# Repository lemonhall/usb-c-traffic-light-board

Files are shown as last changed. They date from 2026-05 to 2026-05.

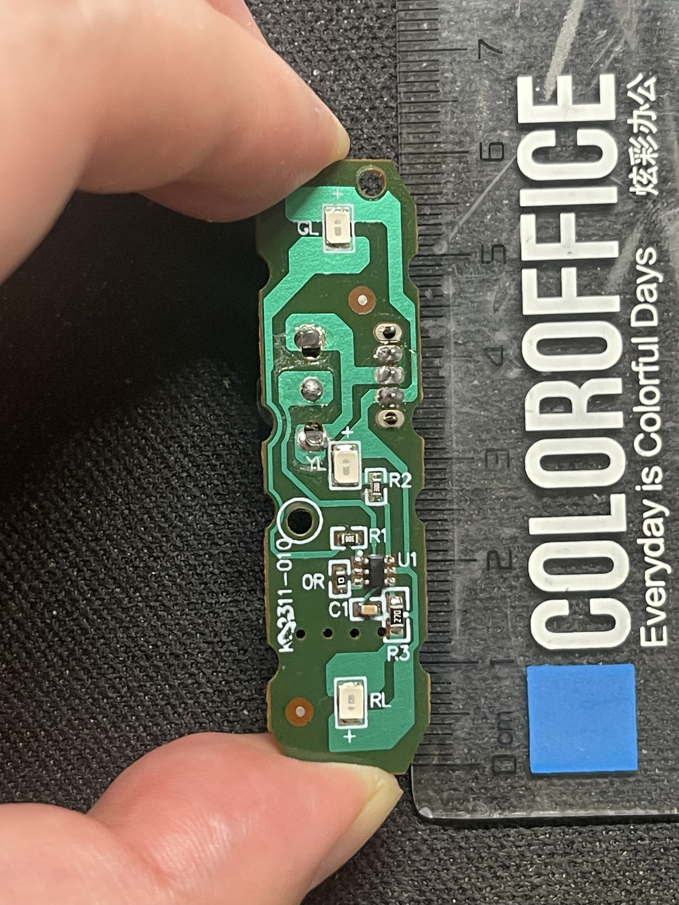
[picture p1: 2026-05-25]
references/正面.jpg

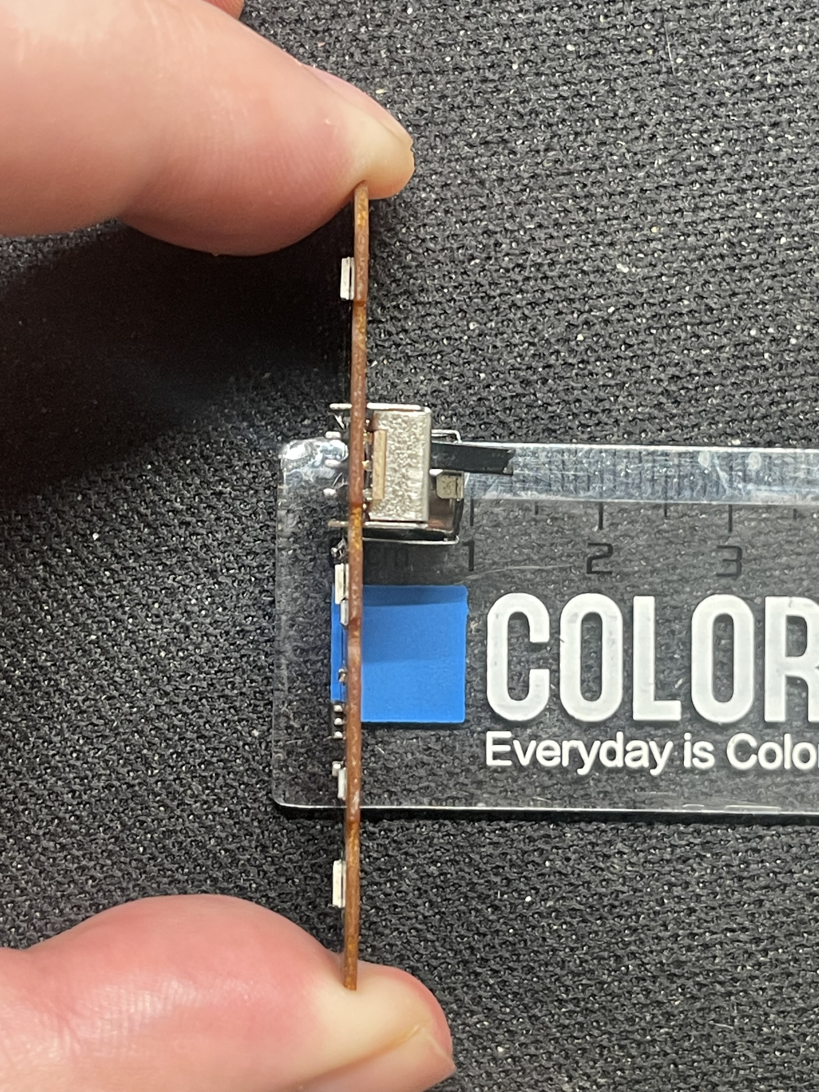
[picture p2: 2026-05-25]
references/侧面.jpg

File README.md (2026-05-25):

# USB-C 红绿灯控制板

这是一个用于替换原红绿灯小板的项目。目标是做一块新的 `57mm x 14mm` 电路板，通过 USB-C 供电，并让电脑通过 USB 串口控制红、黄、绿三颗灯。

## 目标

- 完全替换原来的小电路板。
- 使用 USB-C 供电。
- 通过 USB-C 连接电脑，由电脑控制三颗灯。
- 电脑端识别为虚拟串口，方便脚本控制。
- 尽量避免飞线，最终装配时只使用这一块新板。

## 当前机械假设

- 板长：`57mm`
- 板宽：`14mm`
- 当前板框已经按原板照片改成上下梯形端部和左右半圆避让槽。
- 三颗灯从上到下为：绿、黄、红；灯中心按从板底往上约 `50mm`、`28mm`、`7mm` 复核。
- 上螺丝孔直径 `2mm`，孔边离上端梯形窄边约 `1mm`。
- 下螺丝孔直径 `2mm`，孔中心离板顶约 `33mm`，位于板子左侧、靠近从下往上第二组避让槽。
- USB-C 目标位置对应原拨动开关穿出后壳的位置；原开关伸出背面约 `10mm`，开口宽度约 `10mm`。
- 注意：当前 KiCad 里 `USB_C_Receptacle_G-Switch_GT-USB-7025` 是 `right-angle` 占位封装，不是最终可下单的立式背出 USB-C；最终必须按实物型号替换封装和 3D 机械模型。

## 下一步顺序

1. 机械复核：量原板孔位、缺口、圆角、灯中心坐标、USB-C 后壳开口位置，把板框从当前矩形改成更贴原壳的形状。
2. USB-C 完整性复核：按最终采购的连接器封装，复核 `VBUS`、`GND`、`CC1`、`CC2`、`D+`、`D-`，确认正反插都能稳定供电和通信。
3. 生成生产文件：用 KiCad CLI 导出 Gerber 和钻孔文件，再用 Gerber 预览检查铜层、板框、孔、阻焊和丝印。
4. 小批打样前审查：逐项核对 BOM、封装方向、LED 极性、USB-C 型号、CH552G 供电和下载方式。

当前建议先做第 1 步和第 2 步。它们决定这块板能不能真的塞回外壳，以及插上电脑后能不能稳定识别。

## 电气方案

- 主控：沁恒 `CH552G`，小封装、带原生 USB。
- USB-C：
  - 电脑 USB-C 默认 `VBUS` 提供 `5V`。
  - 本板只作为普通受电设备，不做 USB PD 高压协商。
  - `D+ / D-` 接到主控 USB 引脚。
  - `CC1 / CC2` 各接一个 `5.1k` 下拉电阻到地，只做受电设备。
- 三颗灯：
  - 每颗灯单独串限流电阻。
  - 每颗灯由一个主控 GPIO 控制。
  - 固件可用 PWM 分别控制三颗灯亮度，也可以控制任意组合同时亮、闪烁或呼吸。
  - 第一版按低亮度指示灯设计，目标电流约 `2-5mA`。
- 调试：
  - 预留 `5V`、`GND`、`D+`、`D-`、复位、三路灯控制测试焊盘。

## 串口协议草案

电脑通过虚拟串口发送一行文本命令：

```text
R 1
R 0
Y 1
Y 0
G 1
G 0
A 0
A 1
S 1 0 1
?
```

返回示例：

```text
OK
ERR 1
S R=1 Y=0 G=1
```

## 文件说明

- `docs/hardware/requirements.md`：需求和边界。
- `docs/hardware/bom.md`：第一版物料清单。
- `docs/hardware/pinout.md`：引脚和网络分配。
- `docs/hardware/mechanical-measurement-guide.md`：原板外轮廓和孔位测量指南。
- `docs/hardware/serial-protocol.md`：电脑控制协议。
- `docs/hardware/schematic.md`：完整原理图连接说明。
- `docs/hardware/schematic.svg`：可直接打开查看的完整原理图。
- `docs/hardware/pcb-layout.svg`：第一版 PCB 顶层布局草案。
- `references/original-board-photo.md`：原板照片观察记录。
- `kicad/`：KiCad 工程骨架和第一版板框。
- `firmware/README.md`：固件设计说明。
- `pc-control/traffic_light.py`：电脑端串口控制小脚本。

## 已查资料

- CH552G 是带 USB 的 8 位单片机：https://www.alldatasheet.com/datasheet-pdf/pdf/1147065/WCH/CH552G.html
- LCSC 页面显示 CH552G 常见封装为 SOP-16：https://www.lcsc.com/product-detail/Microcontrollers-MCU-MPU-SOC_WCH-Jiangsu-Qin-Heng-CH552G_C111292.html
- CH552G 资料中包含 USB Type-C CC 控制相关内容：https://www.alldatasheet.net/html-pdf/1147065/WCH/CH552G/2781/41/CH552G.html

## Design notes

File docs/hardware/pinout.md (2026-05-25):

# 引脚和网络分配草案

## USB-C

| 信号 | 连接位置 | 说明 |
| --- | --- | --- |
| USB_C_VBUS | 主控电源 / 板上 `5V` | C1 靠近 USB-C 插座 |
| USB_C_GND | 板上地 | USB-C 外壳附近多打地过孔 |
| USB_D_PLUS | 通过 R4 接主控 USB D+ | 走线尽量短，并和 D- 成对 |
| USB_D_MINUS | 通过 R5 接主控 USB D- | 走线尽量短，并和 D+ 成对 |
| USB_CC1 | `5.1k` 到地 | 声明自己是受电设备 |
| USB_CC2 | `5.1k` 到地 | 声明自己是受电设备 |

## 三路灯控制

以下按 CH552G 的 SOP-16 引脚整理。下单前仍要对照最终采购型号的数据手册和封装丝印再核一次。

| 功能 | 网络名 | 主控物理脚 | 主控端口 | 驱动方式 |
| --- | --- | --- | --- | --- |
| 红灯 | LED_R | 2 脚 | P1.4 | GPIO 输出高电平点亮 |
| 黄灯 | LED_Y | 3 脚 | P1.5 | GPIO 输出高电平点亮 |
| 绿灯 | LED_G | 4 脚 | P1.6 | GPIO 输出高电平点亮 |

## CH552G SOP-16 关键引脚

| 物理脚 | 名称 | 本项目用途 |
| ---: | --- | --- |
| 1 | P3.2 | 预留 |
| 2 | P1.4 | 红灯控制 |
| 3 | P1.5 | 黄灯控制 |
| 4 | P1.6 | 绿灯控制 |
| 5 | P1.7 | 预留 |
| 6 | RST | 复位 / 测试焊盘 |
| 7 | P3.1 | 预留 |
| 8 | P3.0 | 预留 |
| 9 | P1.1 | 预留 |
| 10 | P3.3 | 预留 |
| 11 | P3.4 | 预留 |
| 12 | P3.6 / UDP | USB D+ |
| 13 | P3.7 / UDM | USB D- |
| 14 | GND | 地 |
| 15 | VCC | `5V` |
| 16 | V33 | 内部 USB 稳压输出，接 `100nF` 到地 |

## 测试焊盘

| 焊盘 | 网络名 | 用途 |
| --- | --- | --- |
| TP1 | 5V | 量供电 |
| TP2 | GND | 接地夹 |
| TP3 | USB_D_PLUS | USB 调试 |
| TP4 | USB_D_MINUS | USB 调试 |
| TP5 | RST | 复位 / 烧录辅助 |
| TP6 | LED_R | 红灯信号探针 |
| TP7 | LED_Y | 黄灯信号探针 |
| TP8 | LED_G | 绿灯信号探针 |

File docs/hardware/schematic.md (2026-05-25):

# 完整原理图说明

这份原理图对应文件：

- `docs/hardware/schematic.svg`

可以直接用浏览器、图片查看器或矢量图软件打开。

## 电源

USB-C 的 `VBUS` 作为板上 `5V` 电源。`C1` 是输入储能电容，`C2` 靠近主控 `VCC`，`C3` 靠近主控 `V33`。

CH552G 在 `5V` 供电时：

- `VCC` 接 `5V`。
- `GND` 接地。
- `V33` 接 `100nF` 到地，不直接给外部负载供电。

## USB-C

- `A6` 和 `B6` 合并为 USB D+。
- `A7` 和 `B7` 合并为 USB D-。
- D+ 经过 `R4 22Ω` 接 CH552G 的 `P3.6/UDP`。
- D- 经过 `R5 22Ω` 接 CH552G 的 `P3.7/UDM`。
- `CC1` 经过 `R6 5.1k` 接地。
- `CC2` 经过 `R7 5.1k` 接地。

## 三颗灯

第一版采用“GPIO 输出高电平点亮”的接法：

- `P1.4` 控红灯。
- `P1.5` 控黄灯。
- `P1.6` 控绿灯。

每路结构相同：

```text
主控 GPIO -> 限流电阻 -> LED -> GND
```

第一版限流电阻用 `1k`，适合做室内状态指示。若透光件较暗，可以改为 `680Ω` 或 `470Ω` 后实测亮度。

## 复位和测试点

- `RST` 预留测试焊盘，默认上拉/复位电路按 CH552G 参考设计最终确认。
- 预留 `5V`、`GND`、`D+`、`D-`、`RST`、`红灯`、`黄灯`、`绿灯` 测试点。

## 下单前必须复核

- USB-C 母座封装是否与实际购买型号一致。
- CH552G SOP-16 封装方向和 1 脚标记。
- 三颗灯是否正好对准外壳透光孔。
- 板框缺口、圆角、安装孔是否符合实物。

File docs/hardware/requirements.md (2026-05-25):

# 需求说明

## 产品目标

做一块 USB-C 控制的三灯红绿灯替换板。

## 必须满足

- 板子外形先按 `57mm x 14mm` 处理。
- 完全替换原板，不依赖原来的控制芯片。
- 使用 USB-C 同时完成供电和电脑控制。
- 三颗灯可以独立控制：
  - 红灯
  - 黄灯
  - 绿灯
- 最终装配尽量不飞线。
- 控制协议要能被电脑脚本直接调用。

## 应该满足

- 物料尽量选择国内常见、容易打样和焊接的器件。
- 原理图保持简单，方便手工排查。
- 关键电源和信号都留测试焊盘。

## 第一版不做

- 不做 Wi-Fi。
- 不做蓝牙。
- 不做电池充电。
- 不做 USB PD 协议协商。
- 不做大功率高亮 LED 驱动。
- 在精确尺寸出来前，不强行复刻全部缺口和孔位。

## 仍需补充的机械尺寸

- 三颗灯的中心坐标。
- 安装孔直径和中心坐标。
- 侧边缺口、倒角、圆角尺寸。
- USB-C 插座在外壳里的露出和避让空间。

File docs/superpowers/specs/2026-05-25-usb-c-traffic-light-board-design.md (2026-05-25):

# USB-C 红绿灯控制板设计

## 目的

做一块完整替换原红绿灯小板的新 PCB。新板通过 USB-C 供电，并通过 USB CDC 虚拟串口接受电脑控制。

## 机械范围

第一版板框使用 `57mm x 14mm` 矩形。三颗灯的位置先按照片大致竖向排列，等你提供卡尺尺寸后再精修。板上需要容纳三颗 LED、USB-C 母座、CH552G 主控、USB 阻容、LED 限流电阻和测试焊盘。

## 电气范围

主控使用带原生 USB 的 CH552G，而不是 ESP32，因为本需求不需要 Wi-Fi 或蓝牙。USB-C 提供 `5V` 供电以及 USB2.0 的 `D+ / D-` 数据线。`CC1 / CC2` 使用外置 `5.1k` 下拉电阻声明受电设备。每颗 LED 由一个 GPIO 通过限流电阻独立控制。

## 控制协议

电脑通过虚拟串口发送 ASCII 文本命令，例如 `R 1`、`Y 0`、`G 1`、`A 0`、`S 1 0 1` 和 `?`。板子返回 `OK`、当前状态或解析错误。

## 第一版交付物

- 项目说明。
- 需求说明。
- 物料清单。
- 引脚分配。
- 串口协议。
- KiCad 工程骨架。
- 第一版板框。
- 完整原理图 SVG。
- PCB 顶层布局草案 SVG。
- 电脑端串口控制脚本。

## 风险

- CH552G 的物理引脚必须在最终 KiCad 符号和封装选定后再次核对。
- USB-C 母座封装必须和最终采购型号一致。
- 三颗灯中心、安装孔和缺口需要精确尺寸后才能打样。
- 固件需要先选定一个稳定的 CH55x CDC 示例工程。

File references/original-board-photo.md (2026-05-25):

# 原板照片记录

当前已保存三张参考图：

```text
references/正面.jpg
references/背面.jpg
references/侧面.jpg
```

## 从附件观察到的信息

- 原板是一块很窄的红绿灯小板。
- 三颗贴片 LED 竖向排列。
- 丝印大致如下：
  - 顶部灯附近是 `GL`
  - 中间灯附近是 `YL`
  - 底部灯附近是 `RL`
- 原板上有一个小控制芯片，丝印位置为 `U1`。
- 原板有较大的焊点，也有不规则侧边缺口。
- 外轮廓不是矩形：
  - 两端都有近似梯形倒角，外接宽度 `14mm`，端部窄边约 `10mm`，梯形高度约 `4-5mm`。
  - 两条长边共有 8 个半圆/浅槽避让，左右两两对齐，形成 4 组。
  - 4 组避让槽从板底往上约在 `10mm`、`23mm`、`32mm`、`46mm` 处。
  - 两个大圆孔是螺丝孔，实测孔径为 `2mm`。
- 背面能看到原拨动开关穿出板面，后续 USB-C 应尽量复用这个外壳开口方向，而不是放在板端。
- 侧面照片显示原拨动开关本体明显高出板面；新 USB-C 连接器必须复核高度和外壳干涉。
- 你实测的新板参考尺寸：
  - 长度：`57mm`
  - 宽度：`14mm`

## 当前 KiCad 机械近似

- `scripts/generate_kicad_pcb.py` 已按照片加入第一版近似外轮廓。
- 当前板框仍以 `57mm x 14mm` 为外接矩形基准。
- 上下端倒角按端部窄边 `10mm`、梯形高度 `4.5mm` 建模。
- 已加入两个 `2mm` 螺丝孔：
  - `H1`：靠近绿灯端。
  - `H2`：靠近中部偏黄灯/主控区域。
- 侧边避让槽已按 4 组左右对齐放置：
  - 从板底往上约 `10mm`、`23mm`、`32mm`、`46mm`。
  - 换算到当前 KiCad 坐标约为 `y=47mm`、`34mm`、`25mm`、`11mm`。
- 侧边避让槽深度仍为照片估算，后续需要试装或卡尺数据修正。

## 后续最好补充

- 两个螺丝孔中心距。
- 每个螺丝孔中心到板端、板边的距离。
- USB-C 预期开口中心到板端、板边的距离。

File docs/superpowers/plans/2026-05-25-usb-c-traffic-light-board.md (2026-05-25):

# USB-C 红绿灯控制板实施计划

> 给后续执行者：按任务逐项完成并勾选。每一步都应该留下可检查的文件结果。

**目标：** 建立一套第一版 USB-C 红绿灯控制板项目资料，面向 `57mm x 14mm` 完全替换板。

**架构：** 电路板使用 CH552G 原生 USB 单片机，USB-C 负责供电和数据，三颗 LED 由三个 GPIO 控制。KiCad 先建立工程骨架和板框，详细封装和精确机械位置等拿到卡尺数据后再锁定。

**技术栈：** KiCad、Markdown 硬件文档、Python 电脑端串口脚本。

---

### 任务 1：项目结构和需求

**文件：**
- 创建：`README.md`
- 创建：`docs/hardware/requirements.md`
- 创建：`references/original-board-photo.md`

- [x] **步骤 1：创建项目目录**

运行：

```powershell
New-Item -ItemType Directory -Force -Path E:\development\usb-c-traffic-light-board
```

期望结果：项目目录存在。

- [x] **步骤 2：写入需求文档**

写入 README、硬件需求和原板照片观察记录，明确 `57mm x 14mm` 外形、USB-C 供电控制、原板三灯信息。

### 任务 2：电气草案

**文件：**
- 创建：`docs/hardware/bom.md`
- 创建：`docs/hardware/pinout.md`
- 创建：`docs/hardware/serial-protocol.md`

- [x] **步骤 1：定义第一版物料清单**

列出 USB-C 母座、CH552G、三颗 LED、电阻、电容和测试焊盘。

- [x] **步骤 2：定义 USB 和 GPIO 网络**

记录 `VBUS`、`GND`、`D+`、`D-`、`CC1`、`CC2` 和三路 LED 控制信号。

- [x] **步骤 3：定义串口文本协议**

记录 `R`、`Y`、`G`、`A`、`S` 和 `?` 命令，以及对应返回。

### 任务 3：KiCad 骨架

**文件：**
- 创建：`kicad/usb_c_traffic_light_board.kicad_pro`
- 创建：`kicad/usb_c_traffic_light_board.kicad_sch`
- 创建：`kicad/usb_c_traffic_light_board.kicad_pcb`

- [x] **步骤 1：创建 KiCad 项目文件**

创建 KiCad 项目容器。

- [x] **步骤 2：创建原理图说明页**

创建带项目标题和设计说明的原理图草稿。

- [x] **步骤 3：创建板框**

创建 `57mm x 14mm` 的 `Edge.Cuts` 矩形板框，并加入放置提示。

### 任务 4：电脑端控制辅助

**文件：**
- 创建：`pc-control/traffic_light.py`
- 创建：`firmware/README.md`

- [x] **步骤 1：创建串口控制脚本**

实现一个最小 Python 脚本：向指定串口发送一条 ASCII 命令，并打印一行返回。

- [x] **步骤 2：记录固件行为**

记录上电状态、命令解析流程和可选工具链。

### 任务 5：验证

**文件：**
- 检查所有创建的文件。

- [x] **步骤 1：列出生成文件**

运行：

```powershell
Get-ChildItem -Recurse E:\development\usb-c-traffic-light-board
```

期望结果：计划中的文件都存在。

- [x] **步骤 2：检查中文乱码**

按仓库编码规则运行乱码特征扫描。

期望结果：没有匹配。

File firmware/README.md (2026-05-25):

# 固件说明

目标主控：CH552G。

固件行为：

1. 枚举为 USB CDC 虚拟串口设备。
2. 初始化红、黄、绿三个 GPIO 为输出。
3. 复位后默认三颗灯全灭。
4. 从虚拟串口读取一行 ASCII 命令。
5. 按 `docs/hardware/serial-protocol.md` 解析命令。
6. 返回 `OK`、当前状态，或错误信息。

## 状态流程草案

```text
USB 复位
  -> 初始化时钟和 USB 设备
  -> 初始化 GPIO 输出为低电平
  -> 等待串口命令行
  -> 解析命令
  -> 更新三颗灯状态
  -> 返回执行结果
  -> 等待下一条命令
```

## 构建工具

工具链还没有锁死。实用选择有：

- 沁恒官方 8051 开发流程。
- 基于 SDCC 的 CH55x 开发流程。

第一目标是先找到稳定的 CDC 示例工程；只要串口协议不变，底层工具链后续可以替换。

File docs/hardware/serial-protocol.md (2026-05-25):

# USB 虚拟串口控制协议

传输方式：USB CDC 虚拟串口。

换行：支持 `\n` 或 `\r\n`。

编码：ASCII。

## 命令

| 命令 | 含义 |
| --- | --- |
| `R 1` | 打开红灯 |
| `R 0` | 关闭红灯 |
| `Y 1` | 打开黄灯 |
| `Y 0` | 关闭黄灯 |
| `G 1` | 打开绿灯 |
| `G 0` | 关闭绿灯 |
| `A 1` | 三颗灯全开 |
| `A 0` | 三颗灯全关 |
| `S r y g` | 一次设置红、黄、绿三个状态，每个值为 `0` 或 `1` |
| `?` | 查询当前状态 |

## 返回

| 返回 | 含义 |
| --- | --- |
| `OK` | 命令已接受 |
| `S R=0 Y=0 G=0` | 当前状态 |
| `ERR 1` | 命令或参数无法解析 |

## 上电状态

USB 复位后，三颗灯默认全灭。

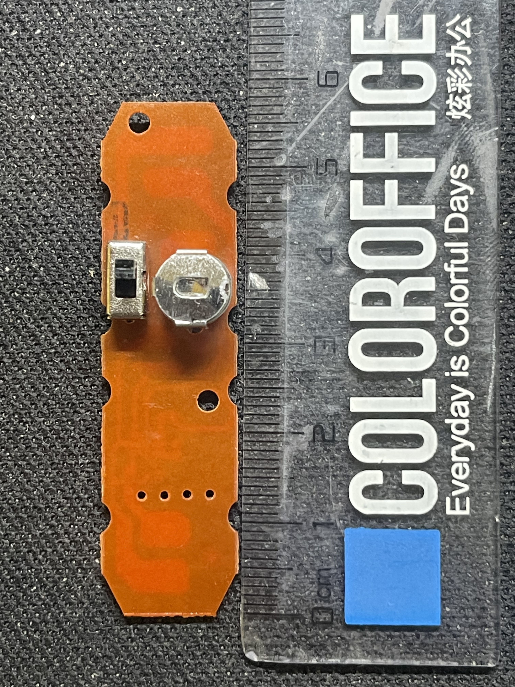
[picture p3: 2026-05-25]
references/背面.jpg

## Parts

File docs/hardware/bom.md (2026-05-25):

# 第一版物料清单

| 位号 | 数量 | 器件 | 封装 | 说明 |
| --- | ---: | --- | --- | --- |
| J1 | 1 | USB-C 母座 | 只接 USB2.0 的贴片座 | 等确认外壳后选择沉板或普通贴片 |
| U1 | 1 | 沁恒 CH552G | SOP-16 | 带原生 USB 的单片机 |
| D1 | 1 | 绿灯 LED | 0805 或 1206 | 按外壳透光孔选择尺寸 |
| D2 | 1 | 黄灯 LED | 0805 或 1206 | 按外壳透光孔选择尺寸 |
| D3 | 1 | 红灯 LED | 0805 或 1206 | 按外壳透光孔选择尺寸 |
| R1 | 1 | 绿灯限流电阻 | 0603 或 0805 | 第一版从 `1k` 起步 |
| R2 | 1 | 黄灯限流电阻 | 0603 或 0805 | 第一版从 `1k` 起步 |
| R3 | 1 | 红灯限流电阻 | 0603 或 0805 | 第一版从 `1k` 起步 |
| R4 | 1 | USB D+ 串联电阻 | 0603 | 第一版按 `22Ω` 预留 |
| R5 | 1 | USB D- 串联电阻 | 0603 | 第一版按 `22Ω` 预留 |
| R6 | 1 | CC1 下拉电阻 | 0603 | `5.1k` 到地 |
| R7 | 1 | CC2 下拉电阻 | 0603 | `5.1k` 到地 |
| C1 | 1 | VBUS 输入电容 | 0805 | `4.7uF` 或 `10uF` |
| C2 | 1 | 主控去耦电容 | 0603 | `100nF`，靠近 U1 |
| C3 | 1 | USB/内部电源去耦 | 0603 | `100nF`，最终按参考设计确认 |
| TP1-TP8 | 8 | 测试焊盘 | 约 `1.0mm` 焊盘 | `5V`、地、USB、复位、三路灯 |

## 说明

- 第一版主控选 CH552G，是因为它小、便宜，并且自带 USB。
- LED 电阻先按室内指示灯亮度设计，实际亮度要结合外壳透光效果再调。
- 如果 USB-C 会频繁插拔，第二版建议加 USB 静电保护器件。
- 当前完整连接图见 `docs/hardware/schematic.svg`。

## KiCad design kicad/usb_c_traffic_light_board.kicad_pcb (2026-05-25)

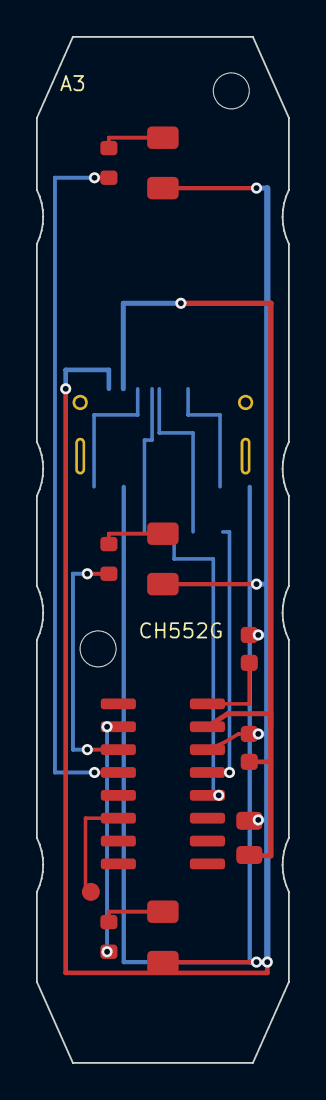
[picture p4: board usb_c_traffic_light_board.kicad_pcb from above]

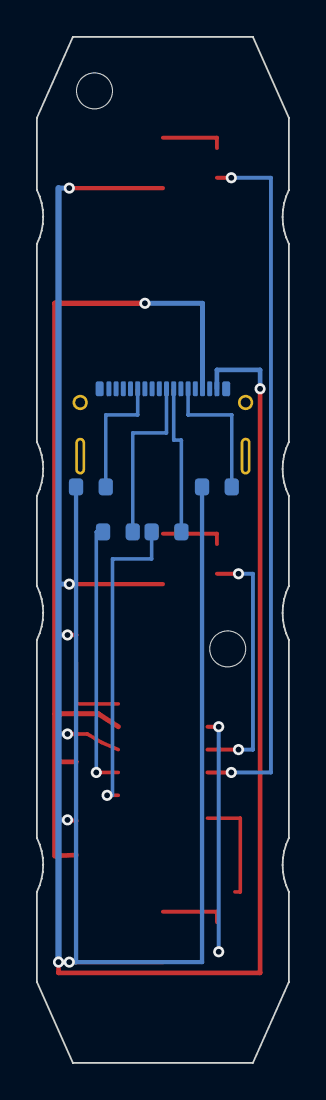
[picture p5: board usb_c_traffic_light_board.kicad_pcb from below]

Board: 2 copper layers, 14.0 x 57.0 mm, 18 parts (5 on the bottom side), 16 nets.

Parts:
C1: 10uF; C_0805_2012Metric
C2, C3: 100nF; C_0603_1608Metric
D1: 绿灯; LED_1206_3216Metric
D2: 橙灯; LED_1206_3216Metric
D3: 红灯; LED_1206_3216Metric
H1: 上螺丝孔; MountingHole_2mm
H2: 下螺丝孔; MountingHole_2mm
J1: 背面USB-C; USB_C_Receptacle_G-Switch_GT-USB-7025
R1, R2, R3: 1k; R_0603_1608Metric
R4, R5: 22R; R_0603_1608Metric
R6, R7: 5.1k; R_0603_1608Metric
TP1: RST; TestPoint_Pad_D1.0mm
U1: CH552G; SOIC-16_3.9x9.9mm_P1.27mm

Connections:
5V: C1.1, C2.1, J1.A4, U1.15
CC1: J1.A5, R6.1
CC2: J1.B5, R7.1
GND: C1.2, C2.2, C3.2, D1.1, D2.1, D3.1, J1.A1, R6.2, R7.2, U1.14
LED_G: R3.1, U1.4
LED_G_A: D1.2, R3.2
LED_R: R1.1, U1.2
LED_R_A: D3.2, R1.2
LED_Y: R2.1, U1.3
LED_Y_A: D2.2, R2.2
RST: TP1.1, U1.6
USB_D+: R4.2, U1.12
USB_D+_CONN: J1.A6, R4.1
USB_D-: R5.2, U1.13
USB_D-_CONN: J1.A7, R5.1
V33: C3.1, U1.16

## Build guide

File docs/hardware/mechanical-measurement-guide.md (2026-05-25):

# 机械复核测量指南

目标是把原板外轮廓、两个螺丝孔、三颗灯中心、USB-C 后壳开口位置复刻到新板上。不要只靠手持尺子量轮廓，误差会很大；优先用可标定图片来描边。

## 推荐方法一：扫描仪

如果有平板扫描仪，这是最稳的方法。

1. 把原板正面朝下放在扫描仪玻璃上，旁边放一把钢尺或游标卡尺。
2. 扫描分辨率设为 `600dpi` 或更高。
3. 导出 `PNG`，不要用会压缩变形的截图。
4. 再把原板背面也扫一张，用来确认背面开关/USB-C 开口对应位置。
5. 文件命名建议：
   - `references/original-board-front-600dpi.png`
   - `references/original-board-back-600dpi.png`

有扫描图以后，可以用已知板长 `57mm` 或板宽 `14mm` 做比例标定，再在 KiCad 里描 `Edge.Cuts`。

## 推荐方法二：手机正射照片

如果没有扫描仪，用手机也可以，但要尽量减少透视变形。

1. 把原板放在白纸上，旁边放钢尺或游标卡尺，尺子要和板子同一平面。
2. 手机镜头尽量正对板子中心，不要斜拍。
3. 用 `2x` 或 `3x` 镜头，手机离远一点拍，能减少边缘畸变。
4. 打开网格线，让板子长边尽量和画面竖线平行。
5. 拍正面、背面各一张，最好再拍一张带外壳开口位置的照片。
6. 不要裁剪，不要加滤镜，直接发原图。

## 必须量的尺寸

用游标卡尺直接量这些关键尺寸即可，不需要把每个斜边都量出来。

| 编号 | 项目 | 怎么量 |
| --- | --- | --- |
| M1 | 板总长 | 顶部最高点到最底部最低点 |
| M2 | 板最大宽 | 左右最宽处 |
| M3 | 上螺丝孔直径 | 孔内径 |
| M4 | 下螺丝孔直径 | 孔内径 |
| M5 | 两孔中心距 | 上孔中心到下孔中心 |
| M6 | 上孔中心到板顶 | 沿板长方向量 |
| M7 | 下孔中心到板底 | 沿板长方向量 |
| M8 | 上孔中心到左边 | 沿板宽方向量 |
| M9 | 下孔中心到左边 | 沿板宽方向量 |
| M10 | 绿灯中心到板顶 | 用灯珠中心估算 |
| M11 | 黄灯中心到板顶 | 用灯珠中心估算 |
| M12 | 红灯中心到板顶 | 用灯珠中心估算 |
| M13 | USB-C 外壳开口中心到板顶 | 按原拨动开关穿壳位置量 |
| M14 | USB-C 外壳开口中心到板左边 | 按原拨动开关穿壳位置量 |

## 外轮廓怎么给

外轮廓不用逐段精确手量。最实用的做法是：

1. 先用扫描图或正射照片描出轮廓。
2. 用 `57mm x 14mm` 标定比例。
3. 再用 M1-M9 这些卡尺尺寸校正孔位和边界。
4. 斜角、侧边缺口、圆弧边按图片描边，优先保证能塞回外壳和螺丝孔对齐。

## 当前已知机械数据

| 项目 | 当前值 |
| --- | --- |
| 板总长 | `57mm` |
| 板最大宽 | `14mm` |
| 端部梯形窄边 | 约 `10mm` |
| 端部梯形高度 | 约 `4-5mm`，当前 KiCad 暂取 `4.5mm` |
| 螺丝孔直径 | `2mm` |
| 上螺丝孔位置 | 孔边离上端梯形窄边约 `1mm`，实际孔位贴近右上倒角 |
| 下螺丝孔位置 | 孔中心离板顶约 `33mm`，位于板左侧，靠近从下往上第二组避让槽 |
| 三颗灯中心 | 从板底往上约 `7mm`、`28mm`、`50mm` |
| 侧边避让槽数量 | `8` 个，左右两两对齐 |
| 侧边避让槽组数 | `4` 组 |
| 避让槽形状 | 向板内吃进去的半圆 |
| 避让槽位置 | 从板底往上约 `10mm`、`23mm`、`32mm`、`46mm` |
| 原拨动开关伸出高度 | 从板背面伸出约 `10mm` |
| 原拨动开关宽度 | 约 `10mm`，和常见 USB-C 口宽度接近 |

## USB-C 机械注意事项

当前 KiCad 工程里的 USB-C 封装是临时占位。已核查 `USB_C_Receptacle_G-Switch_GT-USB-7025` 的 KiCad 描述为 `right-angle, SMT`，它不能代表最终要从背面垂直伸出外壳的 USB-C 结构。

最终下单前必须补齐：

1. 确认实际采购的立式或背出 USB-C 母座型号。
2. 确认接口宽度约 `10mm` 能对齐原拨动开关开口。
3. 确认接口从板背面伸出的高度能替代原开关约 `10mm` 的伸出量。
4. 用该型号的数据手册重画或替换 KiCad footprint。
5. 加 3D 模型或机械标注，从侧面确认接口方向和外壳干涉。

## 拍照时额外注意

- 两个大圆孔是螺丝孔，孔中心距比外形小缺口更重要。
- 板边两侧的小半圆缺口可能是避让塑料柱或卡扣，需要保留大致位置。
- 顶部和底部的斜角不用过度追求 `0.1mm` 精度，能避开外壳干涉即可。
- 三颗灯中心要比丝印位置更重要，因为它们要对准红绿灯外壳的透光窗口。

## 你发给我的最小资料包

最少给这些就能继续画机械版：

1. 正面正射照片或扫描图一张。
2. 背面正射照片或扫描图一张。
3. `M1-M9` 的卡尺尺寸。
4. 如果能量，再补 `M10-M14`。

如果实在量不准，先给图片和 `M1-M5`，我可以先做一个近似轮廓版，再根据你试装反馈微调。

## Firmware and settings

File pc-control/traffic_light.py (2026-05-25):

"""USB-C 红绿灯控制板的电脑端辅助脚本。

用法：
    python traffic_light.py COM7 "S 1 0 0"
    python traffic_light.py COM7 "?"

依赖：
    pip install pyserial
"""

from __future__ import annotations

import argparse
import serial


def send_command(port: str, command: str, baud: int = 115200, timeout: float = 1.0) -> str:
    with serial.Serial(port, baudrate=baud, timeout=timeout) as ser:
        ser.write((command.strip() + "\n").encode("ascii"))
        ser.flush()
        return ser.readline().decode("ascii", errors="replace").strip()


def main() -> None:
    parser = argparse.ArgumentParser()
    parser.add_argument("port", help="串口号，例如 COM7")
    parser.add_argument("command", help='控制命令，例如 "S 1 0 0"')
    parser.add_argument("--baud", type=int, default=115200)
    args = parser.parse_args()

    print(send_command(args.port, args.command, args.baud))


if __name__ == "__main__":
    main()

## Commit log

2026-05-25 第一版本
    [usb_c_traffic_light_board.kicad_pcb, usb_c_traffic_light_board.kicad_sch]
2026-05-25 提交红绿灯控制板阶段性设计
    [usb_c_traffic_light_board.kicad_pcb, usb_c_traffic_light_board.kicad_sch]
2026-05-25 完成红绿灯控制板布线
    [usb_c_traffic_light_board.kicad_pcb]
2026-05-25 完善机械轮廓和测量记录
    [usb_c_traffic_light_board.kicad_pcb]
2026-05-25 补充代理执行和布线流程
2026-05-25 记录机械复核和USB-C风险
2026-05-25 避位槽的深度不够，仍需修改
    [usb_c_traffic_light_board.kicad_pcb]
